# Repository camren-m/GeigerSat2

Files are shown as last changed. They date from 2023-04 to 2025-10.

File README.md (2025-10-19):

# GeigerSat2
Hardware plans, manufacturing details, source code, and FreeCAD documents relating to the GeigerSat2 project, launched aboard 
[Perlan 2's 2023 flight campaign in Argentina](https://perlanproject.org/2023/).

Picture of the finished CubeSat

## Tech stack
At the heart of the CubeSat, we have an Arduino Nano Every running on the Arduino framework, with the firmware code found in ``src/main.cpp``. (the version found on this repo is not the final flight firmware, pending update)

The Arduino Nano Every interacts with an Adafruit ``BMP388``, an Adafruit microSD card module, buzzer, and up to 3 RadiationWatch Type 5
solid state geiger counters. All components (excluding the geiger counters) are soldered to the custom PCB for simplicity, reliability,
and smaller size. The geiger counters are connected through JST-XH connectors on the PCB.

Larger components soldered
Smaller components soldered
The small, solid-state geiger counter used

Power is provided through a 2500mah 3.7V lithium-polymer battery, boosted to 5V through an Adafruit PowerBoost board, and fed into the
Arduino Nano Every's USB port. An option of supplying 7-12V DC to the 2 pin JST-XH header is an alternative. It will be passed directly
to the Arduino Nano Every's VCC pin, and subsqeuently through its on-board voltage regulator.

## The experiment
More to be added soon.
The compounds used to create the two radiation shielding material candidates

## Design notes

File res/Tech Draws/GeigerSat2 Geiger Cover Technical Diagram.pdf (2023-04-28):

These molds will be used to cast the silicone, and the resulted cast will be used as a mold for the epoxy.
Epoxy does not stick to
silicone, and we cannot use the silicone directly as the sulphur in the barium sulfate shielding additive (BaSO4) causes cure inhibition in platinum-cured silicone. However, barium sulfate does not affect epoxy resin.

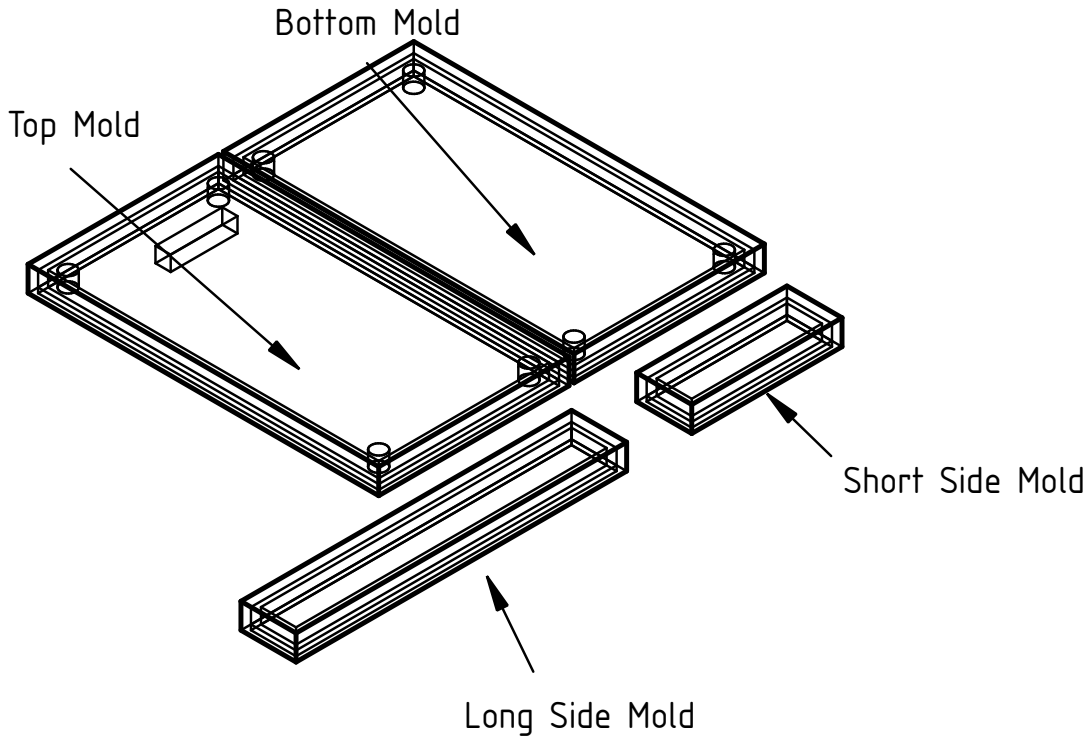
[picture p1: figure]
Top Mold; Bottom Mold; Short Side Mold; Long Side Mold

Once the epoxy has been cured, the resulting casts can be "sandwiched." One top mold will go on the top cavity, in-between the inner and outer cover. You can then place the two short side casts in the short cavities, in-between the screw holes. The two long side casts will be placed in the long cavities, in-between the screw holes. The bottom cast will be placed in the bottom cavity, in-between the geiger counter/inner cover and the top face of the stack plate. You can then insert M3x20 screws into the 4 screw holes, and add M3 nuts if required.

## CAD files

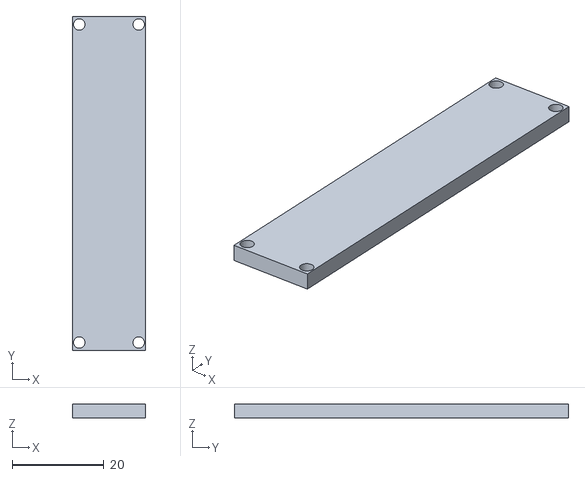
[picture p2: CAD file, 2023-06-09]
cad/Exports/Misc/Double Geiger Spacer.stl
16.0 x 73.0 x 3.00

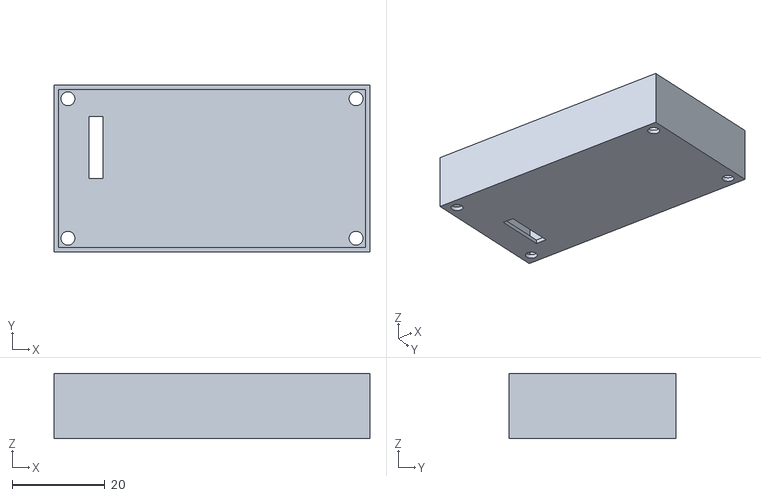
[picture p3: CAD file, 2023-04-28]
cad/Exports/Misc/Geiger Cover/Geiger Cover Outer.stl
68.0 x 36.0 x 14.0

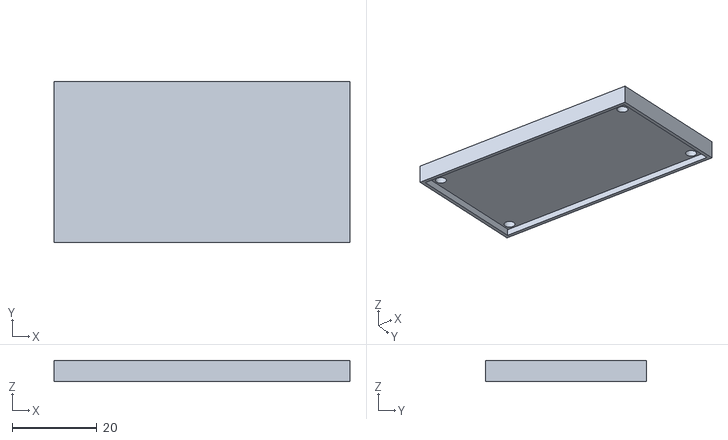
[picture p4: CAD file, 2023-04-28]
cad/Exports/Misc/Geiger Cover/Molds/Bottom/Geiger Cover Bottom Mold.stl
70.0 x 38.0 x 5.00

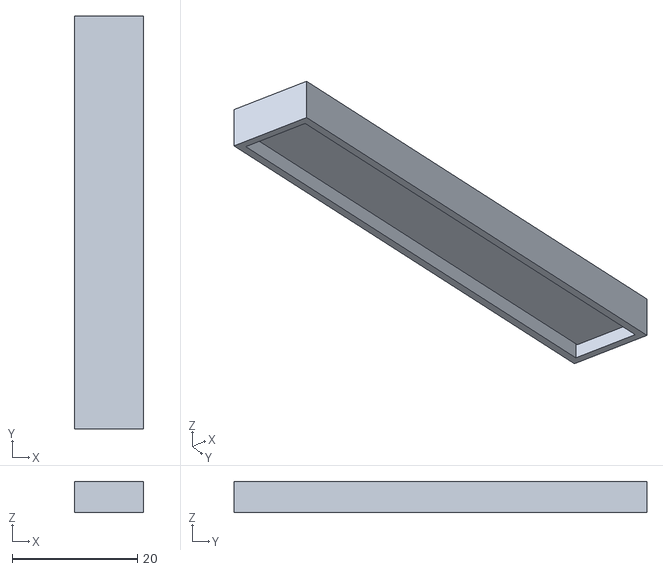
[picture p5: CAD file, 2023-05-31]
cad/Exports/Misc/Geiger Cover/Molds/Side/Geiger Cover Long Side Mold.stl
11.0 x 66.0 x 5.00

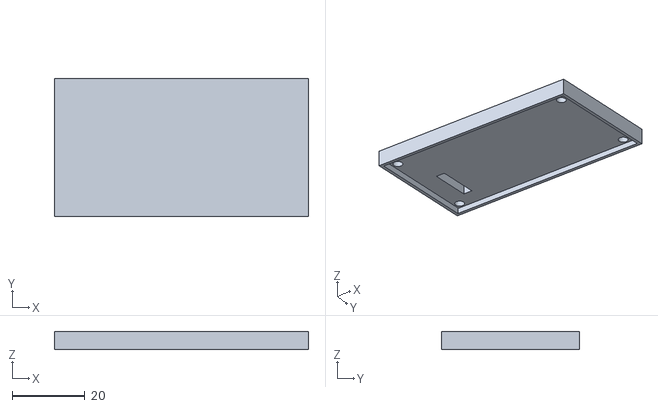
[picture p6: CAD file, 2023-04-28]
cad/Exports/Misc/Geiger Cover/Molds/Top/Geiger Cover Top Mold.stl
70.0 x 38.0 x 5.00

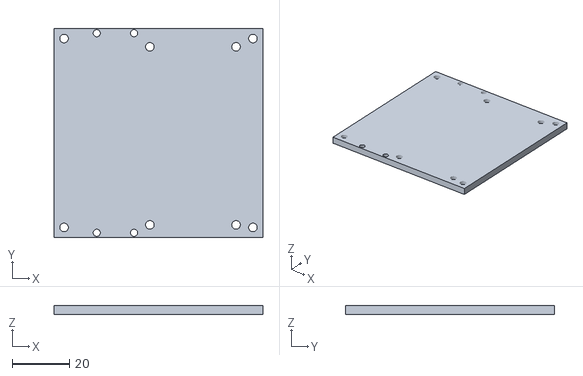
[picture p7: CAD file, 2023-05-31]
cad/Exports/Stack Layers/Sensor Stack Layer 1.stl
72.8 x 72.8 x 3.00

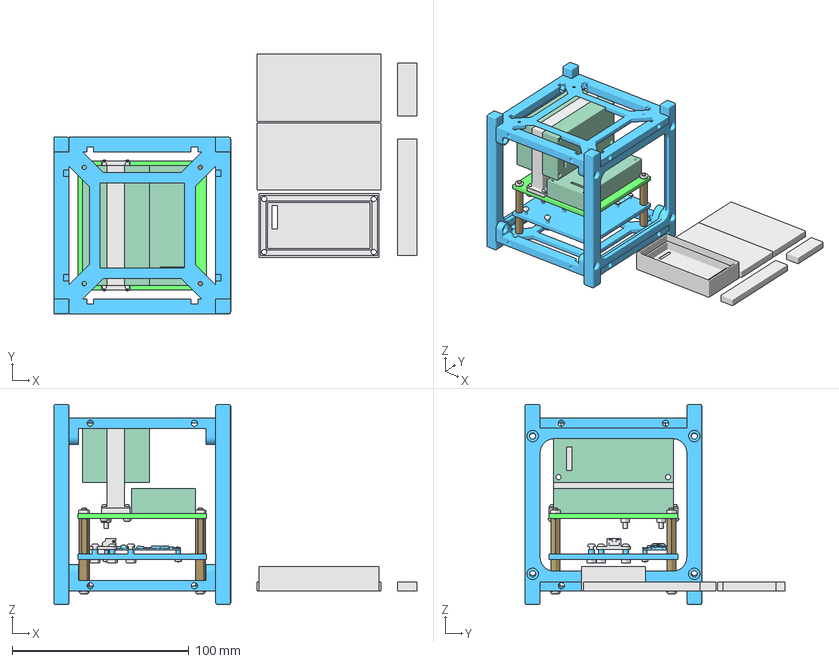
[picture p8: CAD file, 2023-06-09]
cad/GeigerSat2.FCStd
205.5 x 147.0 x 113.5 mm
Stack Layer 1 Standoffs
Stack Layer 2 Standoffs
Stack Screws
Battery Charger Screws
Arduino Screws
SD Reader Screws
Double Geiger Mount Screws
Stack Nuts
SD Reader Nuts
Arduino Nuts
Battery Charger Nuts
BMP388 Nuts
Microcontroller & Power Stack Plate
Sensor Stack Layer 1
Control Geiger Cover
BaSO4 Geiger Cover
Bi2O3 Geiger Cover
Double Geiger Holder
Adafruit Lipo Charger
Arduino Nano Every
ISO2009-M2.5x8_
ISO2009-M2.5x8_001
Geiger Cover Outer
Geiger Cover Inner
Top Mold
Bottom Mold
Short Side Mold
Long Side Mold
Double Geiger Spacer
Cubesat_Bottom_Frame
Cubesat_Side_Frame_Plain
Cubesat_Side_Frame_Plain001
Cubesat_Bottom_Frame001

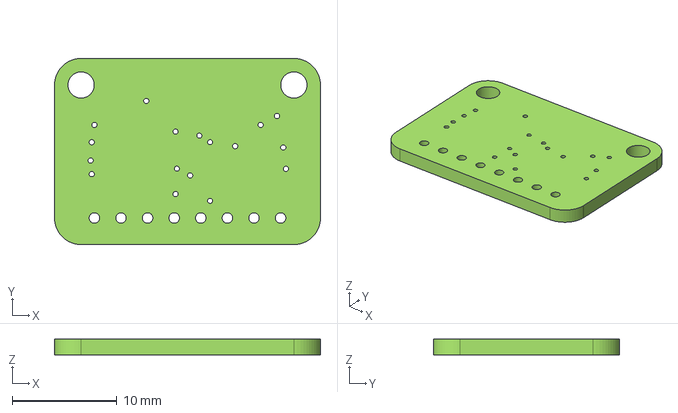
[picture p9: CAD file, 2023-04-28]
cad/Siblings/Adafruit BMP388 QT Rev1/Exports/Adafruit BMP388 QT Rev1.step
25.4 x 17.8 x 1.50 mm

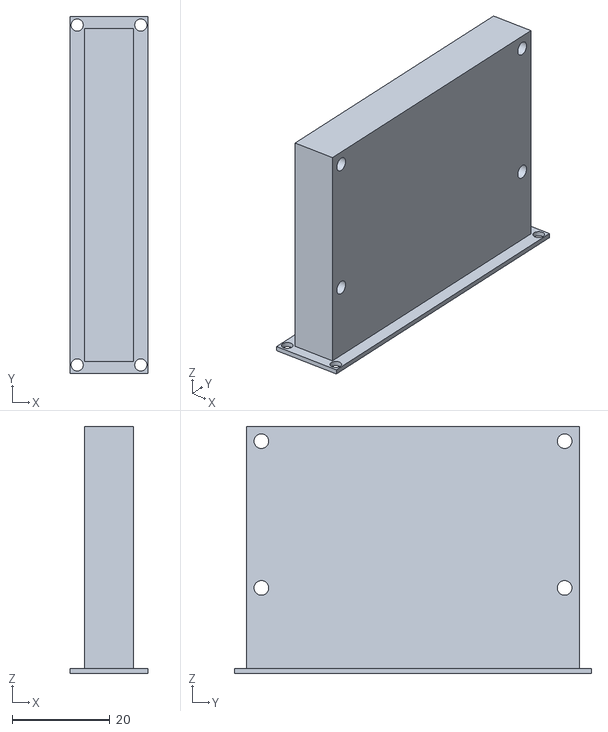
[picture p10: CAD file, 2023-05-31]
cad/Exports/Misc/Double Geiger Holder.stl
16.0 x 73.0 x 50.5

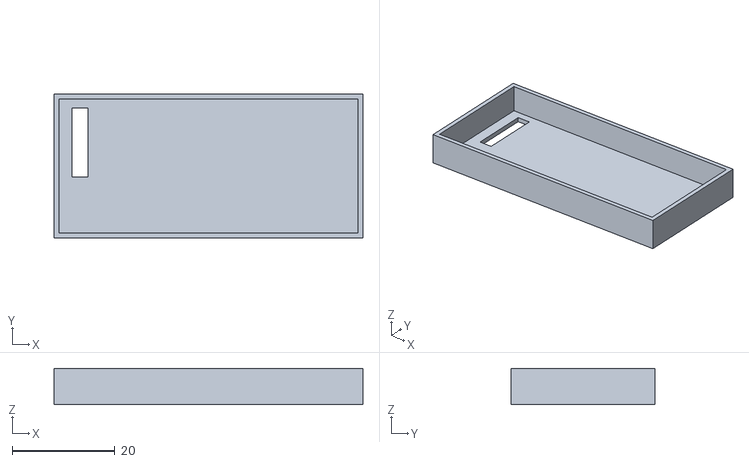
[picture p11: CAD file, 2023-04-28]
cad/Exports/Misc/Geiger Cover/Geiger Cover Inner.stl
60.0 x 28.0 x 7.00

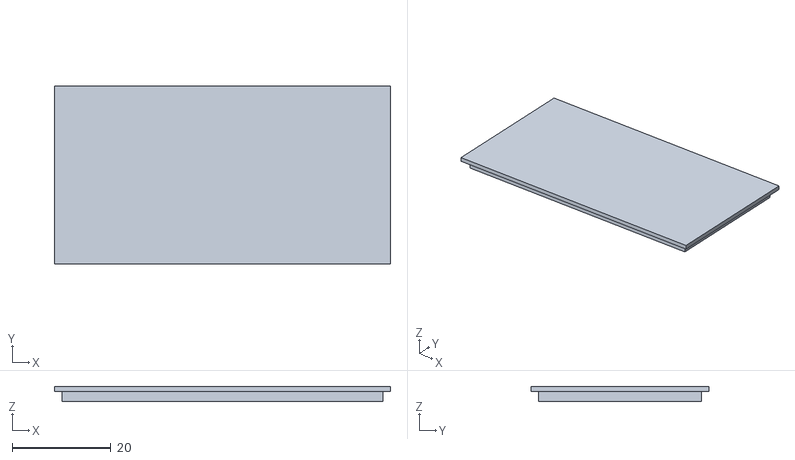
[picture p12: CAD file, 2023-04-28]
cad/Exports/Misc/Geiger Cover/Molds/Bottom/Geiger Cover Bottom Mold Cover.stl
68.0 x 36.0 x 3.00

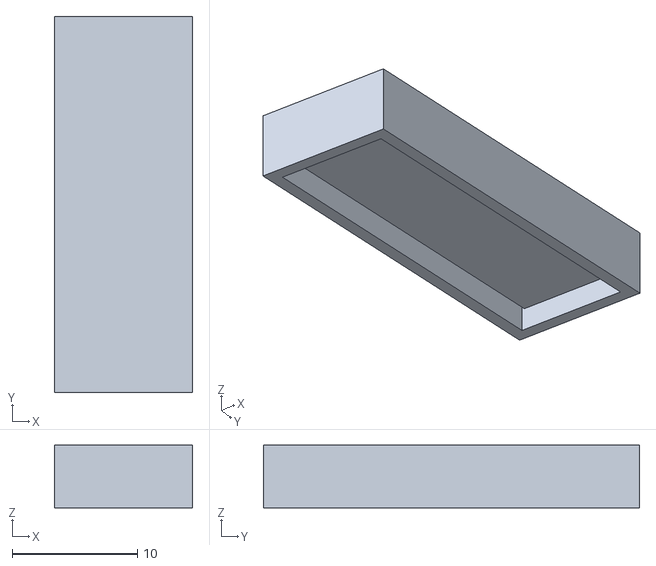
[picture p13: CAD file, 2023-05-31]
cad/Exports/Misc/Geiger Cover/Molds/Side/Geiger Cover Short Side Mold.stl
11.0 x 30.0 x 5.00

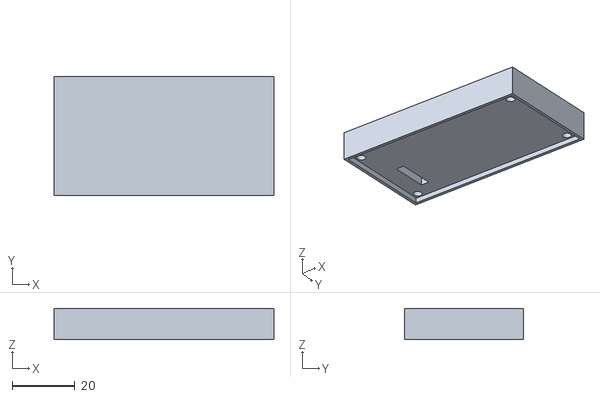
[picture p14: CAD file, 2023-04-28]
cad/Exports/Misc/Geiger Cover/Molds/Top/GeigerSat Cover Top Mold.stl
70.0 x 38.0 x 10.0

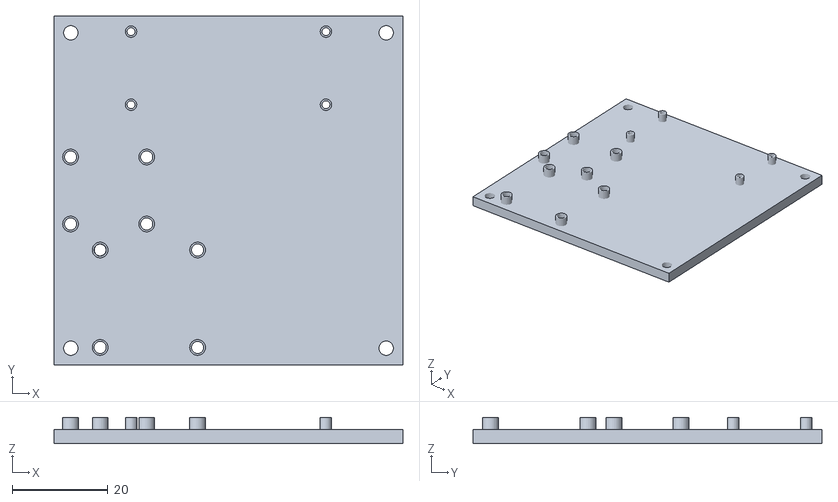
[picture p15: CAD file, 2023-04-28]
cad/Exports/Stack Layers/Microcontroller Stack Layer.stl
72.8 x 72.8 x 5.50

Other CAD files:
cad/Exports/Misc/Breadboard Mounting Plate.stl
cad/Exports/Misc/Geiger Cover/Molds/Side/Geiger Cover Side Mold.stl
cad/Exports/Misc/Geiger Cover/Molds/Top/Geiger Cover Top Mold Cover.stl
cad/Exports/Misc/Geiger Cover/Molds/Side/Geiger Cover Side Mold Cover.stl
cad/Siblings/Adafruit BMP388 QT Rev1/Adafruit BMP388 QT Rev1.FCStd

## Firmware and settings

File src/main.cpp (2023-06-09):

/**
  main.cpp
  4/11/2023
  © Camren Mumme 2023
**/

// Preprocessor Macros
#include "RadiationWatch.h"
#include "Arduino.h"
#include "SPI.h"
#include "SD.h"
#include "Adafruit_Sensor.h"
#include "Adafruit_BMP3XX.h"
#include "pitches.h"
#define SEALEVELPRESSURE_HPA (1013.25) // CHANGE TO NEAREST WEATHER OBSERVATION STATION (E.G AIRPORT AWOS) SEA LEVEL PRESSURE BEFORE LAUNCH TO ENSURE PROPER ALTITUDE REPORTING

// Static Variables
RadiationWatch ControlGeiger(4,5);
RadiationWatch BariumGeiger(6,7);
RadiationWatch BismuthGeiger(8,9);
Adafruit_BMP3XX Altimeter;

int AliveNotes[] = {
  NOTE_C5,
};
int AliveDurations[] = {
  60,
};

int StartupNotes[] = {
  NOTE_A4, 0,  NOTE_A4, 0,  NOTE_A4, 0,  NOTE_F4, 0, NOTE_C5, 0,  NOTE_A4, 0,  NOTE_F4,
};
int StartupDurations[] = {
  50, 20, 50, 20, 50, 20, 40, 5, 20, 5,  60, 10, 40, 
};

int ErrorNotes[] = {
  NOTE_A4, 0,  NOTE_F4,
};
int ErrorDurations[] = {
  60, 10, 40, 
};

// Dynamic Variables
File CurrentFile;
unsigned long InitTime = 0;

// Functions
void PlayStartupTone() {
  for (int thisNote = 0; thisNote < 13; thisNote++) {

    // to calculate the note duration, take one second divided by the note type.
    //e.g. quarter note = 1000 / 4, eighth note = 1000/8, etc.
    int noteDuration = 1000 / StartupDurations[thisNote];
    tone(3, StartupNotes[thisNote], noteDuration);

    // to distinguish the notes, set a minimum time between them.
    // the note's duration + 30% seems to work well:
    int pauseBetweenNotes = noteDuration * 1.3;
    delay(pauseBetweenNotes);
    // stop the tone playing:
    noTone(3);
  }
}

void PlayErrorTone() {
  for (int thisNote = 0; thisNote < 3; thisNote++) {

    // to calculate the note duration, take one second divided by the note type.
    //e.g. quarter note = 1000 / 4, eighth note = 1000/8, etc.
    int noteDuration = 1000 / ErrorDurations[thisNote];
    tone(3, ErrorNotes[thisNote], noteDuration);

    // to distinguish the notes, set a minimum time between them.
    // the note's duration + 30% seems to work well:
    int pauseBetweenNotes = noteDuration * 1.3;
    delay(pauseBetweenNotes);
    // stop the tone playing:
    noTone(3);
  }
}

void PlayAliveTone() {
  for (int thisNote = 0; thisNote < 13; thisNote++) {

    // to calculate the note duration, take one second divided by the note type.
    //e.g. quarter note = 1000 / 4, eighth note = 1000/8, etc.
    int noteDuration = 1000 / AliveDurations[thisNote];
    tone(3, AliveNotes[thisNote], noteDuration);

    // to distinguish the notes, set a minimum time between them.
    // the note's duration + 30% seems to work well:
    int pauseBetweenNotes = noteDuration * 1.3;
    delay(pauseBetweenNotes);
    // stop the tone playing:
    noTone(3);
  }
}


void Log(String Message) {
  CurrentFile.close();
  CurrentFile = SD.open("system.log", FILE_WRITE); 
  if(!CurrentFile) {
    Serial.print(F("["));
    Serial.print(millis()-InitTime);
    Serial.println(F("]        WARN: Failed to open logfile."));
    PlayErrorTone();
  }
  CurrentFile.print(F("["));
  CurrentFile.print(millis()-InitTime);
  CurrentFile.print(F("]        "));
  CurrentFile.println(Message);
  CurrentFile.close();

  Serial.print(F("["));
  Serial.print(millis()-InitTime);
  Serial.print(F("]       "));
  Serial.println(Message);
}

void WipeFile(String TargetFile) {  
  CurrentFile.close();
  if(!SD.exists(TargetFile)) return;
  SD.remove(TargetFile);
}

void CreateCSVHeader(String TargetFile) {
  CurrentFile.close();
  CurrentFile = SD.open(TargetFile, FILE_WRITE);

  CurrentFile.println(F("Time,Altitude,Count,CPM,uSvh,Error"));

  CurrentFile.close();
}

void LogReading(RadiationWatch Geiger, String CSVFile) {
  Log(CSVFile + " reading: " + String(Geiger.radiationCount()) + " counts " + String(Geiger.cpm()) + " CPM " + String(Geiger.uSvh()) + " uSv/h +/- " + String(Geiger.uSvhError()));
  
  CurrentFile.close();
  CurrentFile = SD.open(CSVFile, FILE_WRITE);
  CurrentFile.print(millis()-InitTime);
  CurrentFile.print(F(","));
  CurrentFile.print(Altimeter.readAltitude(SEALEVELPRESSURE_HPA));
  CurrentFile.print(F(","));
  CurrentFile.print(Geiger.radiationCount());
  CurrentFile.print(F(","));
  CurrentFile.print(Geiger.cpm());
  CurrentFile.print(F(","));
  CurrentFile.print(Geiger.uSvh());
  CurrentFile.print(F(","));
  CurrentFile.println(Geiger.uSvhError());
  CurrentFile.close();
}

void ControlGeigerRadiation() {
  LogReading(ControlGeiger, "control.csv");
}

void BariumGeigerRadiation() {
  LogReading(BariumGeiger, "barium.csv");
}

void BismuthGeigerRadiation() {
  LogReading(BismuthGeiger, "bismuth.csv");
}

void SetupGeiger(RadiationWatch *Geiger, String LogName, void (*RadiationCallback)(void), String Name) {
  WipeFile(LogName);
  CreateCSVHeader(LogName);
  Geiger->setup();
  Geiger->registerRadiationCallback(RadiationCallback);
  Log(Name+" setup");
}

void setup() {
  Serial.begin(9600);
  while(!Serial) { };
  Serial.println(F("Hello! Please send any serial message to begin initialization."));
  Serial.println(F("ANY DATA ON THE SD CARD WILL BE WIPED"));
  Serial.println(F("-------------------------------------------------------------"));
  PlayAliveTone();

  while(Serial.available() == 0) { };
  Serial.println(F("Proceeding..."));

  if (!SD.begin(10)) {
    Serial.println(F("SD initialization failed. Aborting."));
    PlayErrorTone();
    while (1);
  }

  InitTime = millis();

  CurrentFile.close();
  File InitLog = SD.open("system.log", FILE_WRITE);
  if(!InitLog) {
    Log("FATAL: Failed to open logfile on init. Aborting.");
    PlayErrorTone();
    while(1) { }
  }
  InitLog.close();
  

  WipeFile("system.log");
  Log(F("SD initialization successful."));

  if (!Altimeter.begin_I2C()) {
    Log(F("Altimeter I2C initialization failed. Aborting."));
    PlayErrorTone();
    while (1);
  }
  Altimeter.setTemperatureOversampling(BMP3_OVERSAMPLING_8X);
  Altimeter.setPressureOversampling(BMP3_OVERSAMPLING_4X);
  Altimeter.setIIRFilterCoeff(BMP3_IIR_FILTER_COEFF_3);
  Altimeter.setOutputDataRate(BMP3_ODR_50_HZ);
  Log(F("Altimeter I2C initialization successful."));

  SetupGeiger(&ControlGeiger, "control.csv", &ControlGeigerRadiation, "Control Geiger");
  SetupGeiger(&BariumGeiger, "barium.csv", &BariumGeigerRadiation, "Barium Geiger");
  SetupGeiger(&BismuthGeiger, "bismuth.csv", &BismuthGeigerRadiation, "Bismuth Geiger");

  Log(F("Welcome! GeigerSat2 initialized."));
  Log(F("Copyright (c) 2023"));
  Log(F("   Camren Mumme. All Rights Reserved"));
  PlayStartupTone();
}

void loop() {
  if (!Altimeter.performReading()) {
    Log("Failed to perform alimeter reading. Altimeter data may not be accurate.");
    PlayErrorTone();
  }
  ControlGeiger.loop();
  BariumGeiger.loop();
  BismuthGeiger.loop();
}

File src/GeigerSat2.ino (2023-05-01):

/**
  GeigerSat2.ino
  4/28/2023
  © Camren Mumme 2023
**/

// Includes
#include "include/LoggingManager.h"
#include "include/CommandManager.h"
#include "include/AltimeterManager.h"
#include "include/GeigerManager.h"

namespace GeigerSat2 {
    bool Initialized = false;

    void Initialize() {
        Serial.println("Proceeding with initialization.");
        LoggingManager::Start();
        LoggingManager::Log("Hello! Starting our tests and subsystem initializations now.");
        AltimeterManager::Start();
        GeigerManager::Start();

        LoggingManager::Log("GeigerSat2 initialized. Welcome!");
        LoggingManager::Log("   Copyright (c) 2023 Camren Mumme");

        Initialized = true;
    }
}

void setup() {
    Serial.begin(9600);
    while(!Serial) { }

    Serial.println("GeigerSat2 ready for initialization. Send init command to initialize.");
    Serial.println("------------------------------------------------------------------------");
}

void loop() {
    CommandManager::Update();

    if(CommandManager::InitializeCommandRun && !GeigerSat2::Initialized) {
        GeigerSat2::Initialize();
    }
    if(!GeigerSat2::Initialized) return;
    GeigerManager::Update();
    LoggingManager::Update();
}

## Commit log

2023-05-01 Revert "some stuff again"
    This reverts commit 03595f0e07972f1a53c05aeb73e88f2fd96d4782.
    [GeigerSat2.ino]
2023-05-01 Revert "Refactor file structure"
    This reverts commit 28da1c18f24edc6bad8f73c86be7aba91b1ea44a.
    [GeigerSat2.ino]
2023-05-03 convert to platformio and fix bugs
    [main.cpp]
2023-05-03 Remove verbose serial print
2023-05-31 Geiger Related Models - Revise for new PCB-based design
    [Double Geiger Holder.stl, Geiger Cover Long Side Mold.stl, Geiger Cover Short Side Mold.stl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]
2023-06-09 CAD - Double Geiger Spacer
    [Double Geiger Spacer.stl, GeigerSat2.FCStd]
